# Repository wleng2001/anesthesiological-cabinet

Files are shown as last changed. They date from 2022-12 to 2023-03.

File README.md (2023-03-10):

# Anesthesiological-cabinet
 It's project of anesthesiological cabinet. Parts are saved in sldprt format. 
## Consist
It's consist of:
* welded body
* rack with height regulation with screw
* four wheel with bearings (it can rotate in 360°)
* runner for drawer

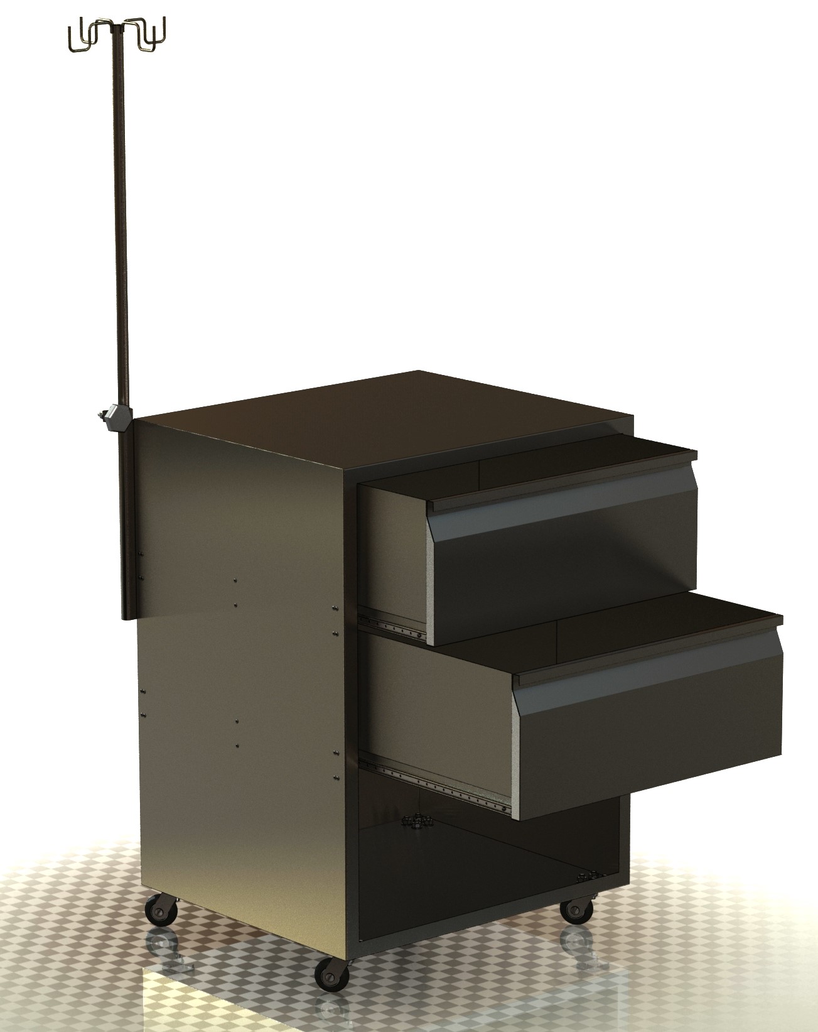
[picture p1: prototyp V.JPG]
It's photo of anesthesiological cabinet rendered in SolidWorks


What means normalized names of files:
* anc-1 it's main assembly
* anc-1-0001-0001 It's wheel assembly
	- anc-1-0001-0001-0001 It's bearing of the wheel assembly
	- anc-1-0001-0001-0002 It's fork fixing
	- anc-1-0001-0001-0003 It's rubbery pad
	- anc-1-0001-0001-0004 It's fork
	- anc-1-0001-0001-0005 It's special screw for wheel
	- anc-1-0001-0001-0006 It's wheel
	- anc-1-0001-0001-0007 It's tyre
* anc-1-0001-0002 It's rack assembly
* anc-1-0001-0003 it's drawer with runner assembly
	- anc-1-0001-0003-0001 It's drawer
	- anc-1-0001-0003-0002 It's fixing of drawer
	- anc-1-0001-0003-0003 It's rivet which fix runner to fixing of drawer
	- anc-1-0001-0003-0004 It's runner assembly
	- anc-1-0001-0003-0005 It's rivet which fix drawer to runner
* anc-1-0001-0004 It's corpus of cabinet
* anc-1-0001-0005 It's rivets, which fits drawer with runner to corpus.
* anc-1-0001-0006 It's rivets, which fits rack to corpus.
* anc-1-0001-0007 It's screw cover.

It's video, where you can see how is build wheel:
https://user-images.githubusercontent.com/112073988/213305082-b9180d91-3ac0-4ed8-8724-1e6955fea45c.mp4

In the technical drawing below you can see main assembly.
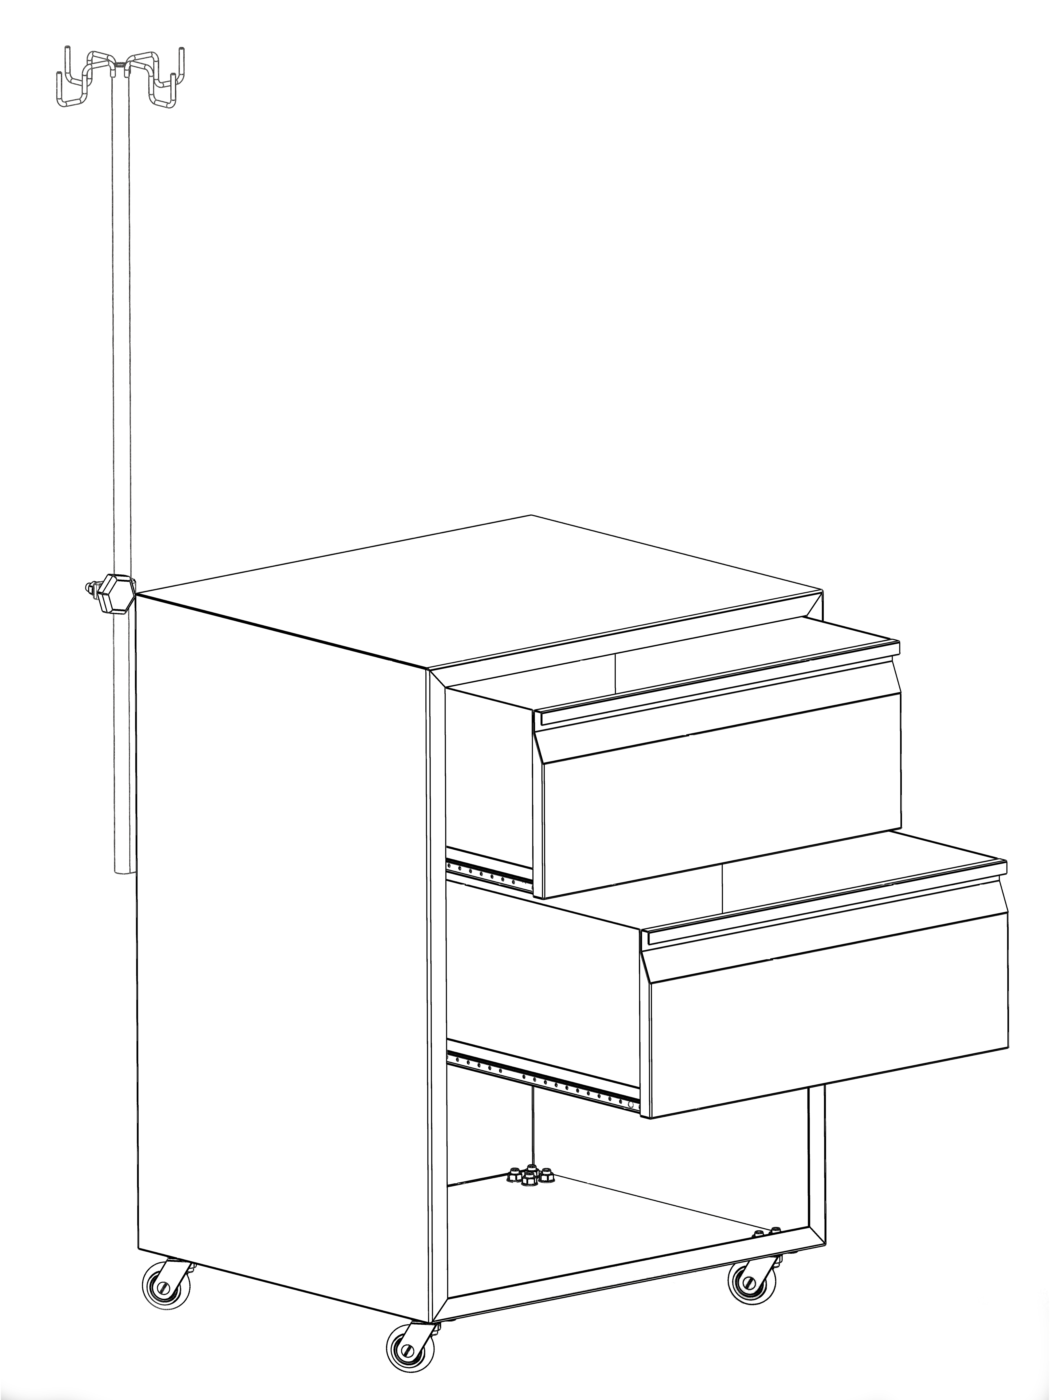
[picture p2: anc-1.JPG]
It's technical drawing of anesthesiological cabinet created in SolidWorks


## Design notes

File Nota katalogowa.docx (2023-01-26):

# Szafka anestezjologiczna anc-1

Nota katalogowa

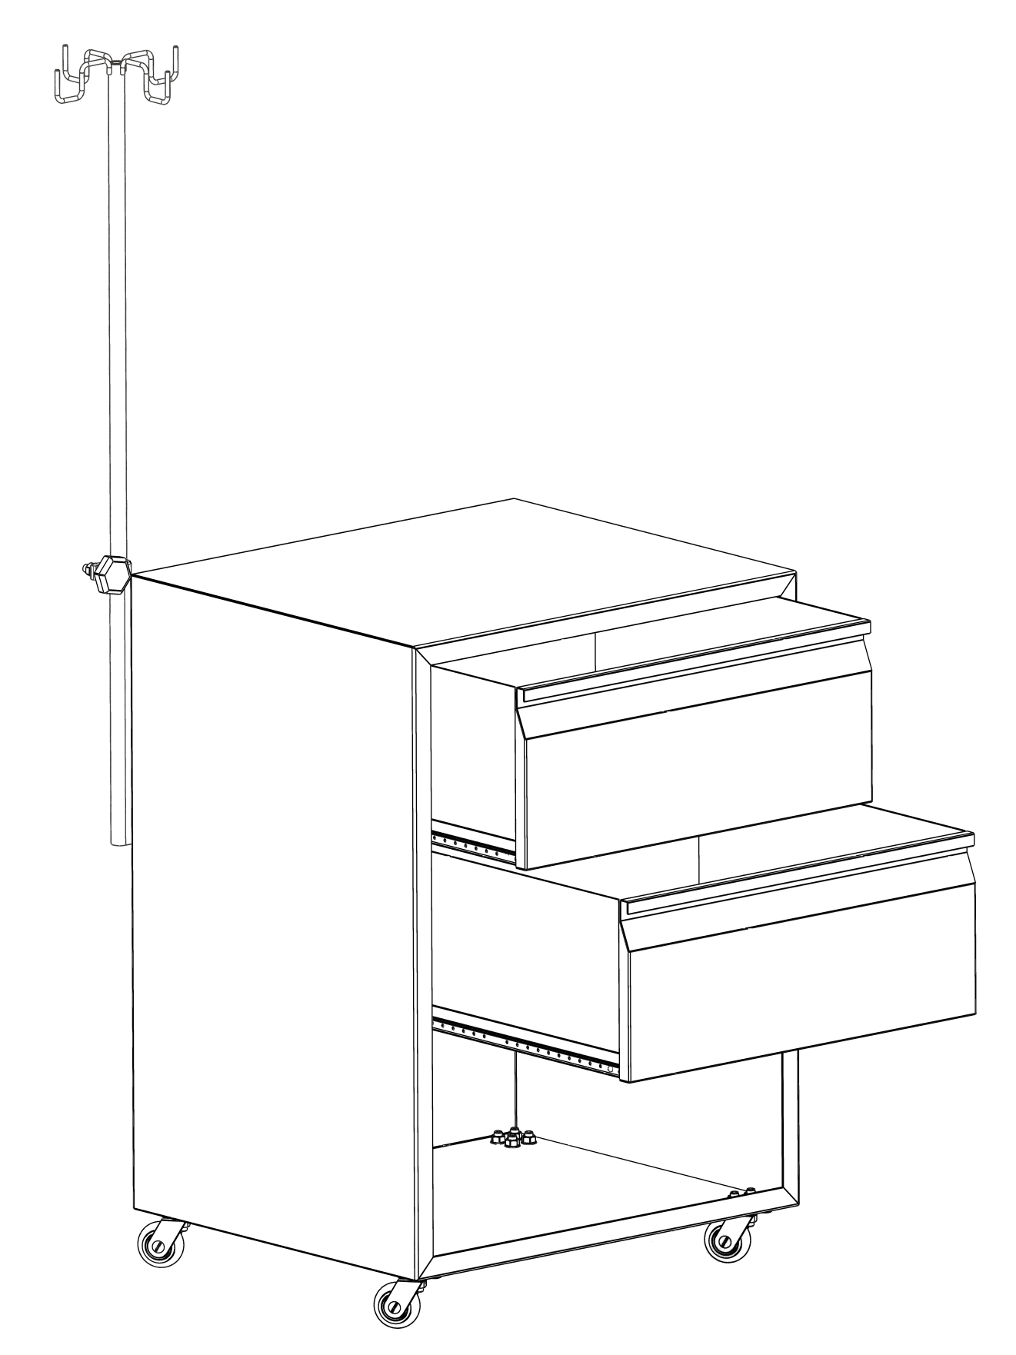
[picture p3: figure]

# Opis

Szafka dedykowana jest do użytku na salach operacyjnych dzięki zastosowaniu wysokiej klasy i wygodnej w czyszczeniu szczotkowanej stali nierdzewnej oraz wartościom użytkowym wynikającym z zastosowania wieszaka na kroplówki z szeroką regulacją wysokości oraz wysuwającym się daleko szufladom.

# Budowa szafki

Szafka składa się z czterech podstawowych elementów:

- korpusu,
- wózków w ilości czterech sztuk,
- szuflad w ilości dwóch sztuk,
- wieszaka.

Wózki wyposażone są w łożyska kulkowe a obrót wokół własnej osi opiera się w nich na łożyskach ślizgowych. Opona zbudowana jest z gumy zapewniając lepszą przyczepność wózka do podłoża oraz redukcję nierówności podczas przemieszczania szafki. Dodatkowe tłumienie nierówności zapewnia gumowa podkładka umieszczona na mocowaniu widelca. Wózki te zostały przymocowane do korpusu przy pomocy śrub M10.

Korpus ma długość 59cm, szerokość 69cm oraz wysokość 90cm i zbudowany jest z jednego arkusza 1mm giętej blachy spawanej na krawędziach w celu zapewnienia sztywności oraz nie pozwolenia na dostawanie się ewentualnych zanieczyszczeń do szuflad.

Szuflady wysuwają się na prowadnicach opartych na łożyskach kulkowych. Głębokość ich wynosi 25,6cm a długość 58cm . Przymocowane zostały do korpusu przy pomocy jednostronnych nitów.

Wieszak zapewnia regulację w zakresie od 102cm do 170cm od podłoża. Unieruchamia się go przy pomocy pokrętła umieszczonego tak, aby regulacja była jak najwygodniejsza. Przymocowany został do korpusu przy pomocy nitów jednostronnych.

Cała szafka waży 35kg a jej wymiary gabarytowe wynoszą na szerokość 82cm wysokość 138cm a długość 114cm.

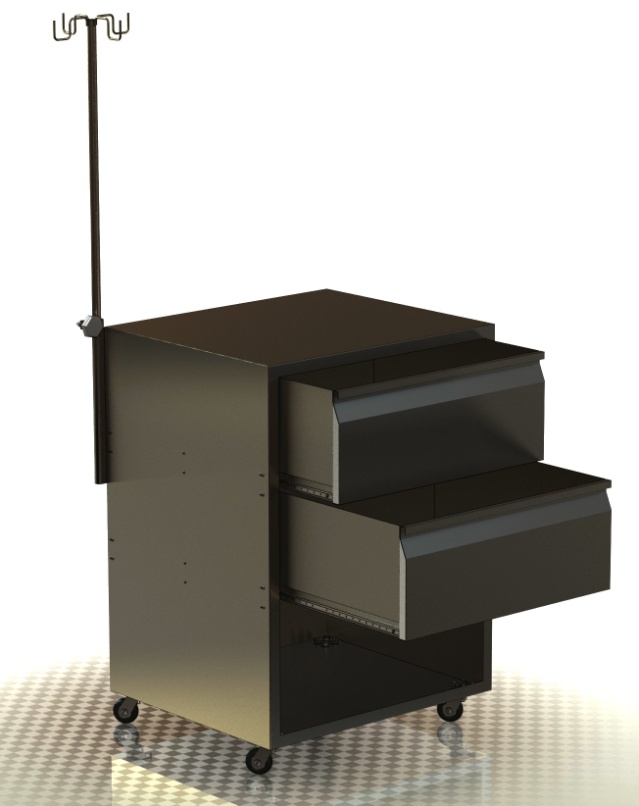
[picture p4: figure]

Zdjęcie 1 przedstawia szafkę w widoku od lewej.

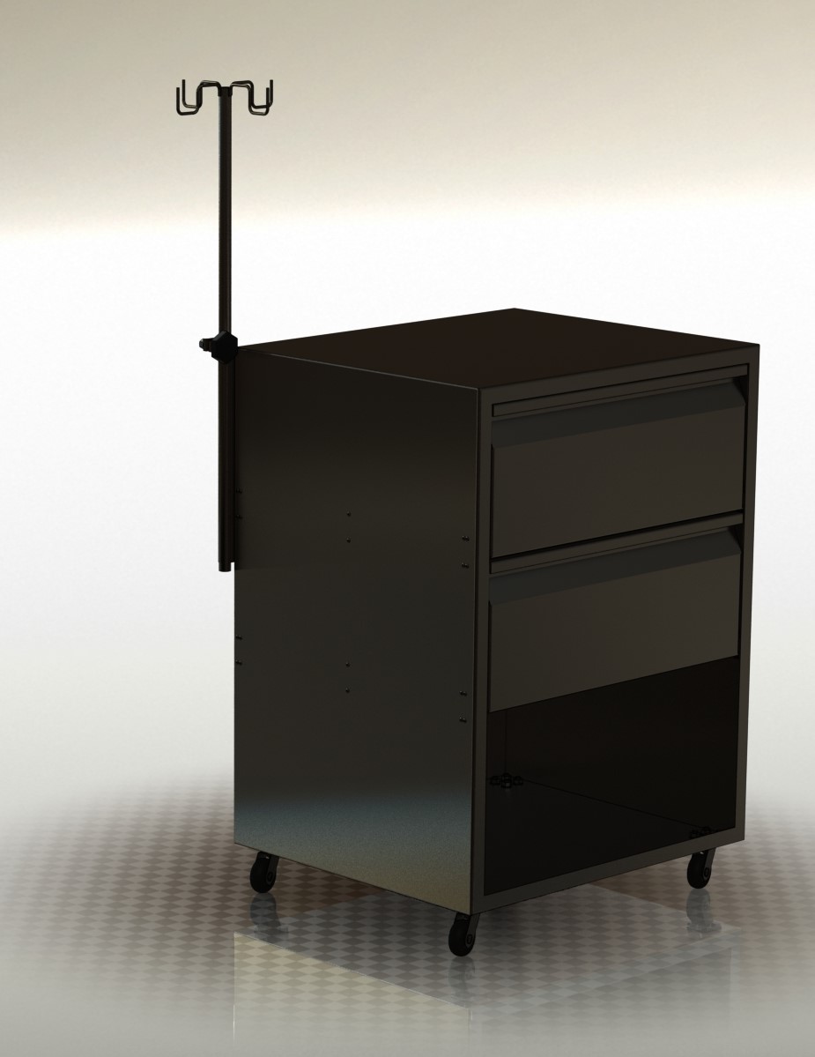
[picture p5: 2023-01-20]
prototyp IVa.JPG

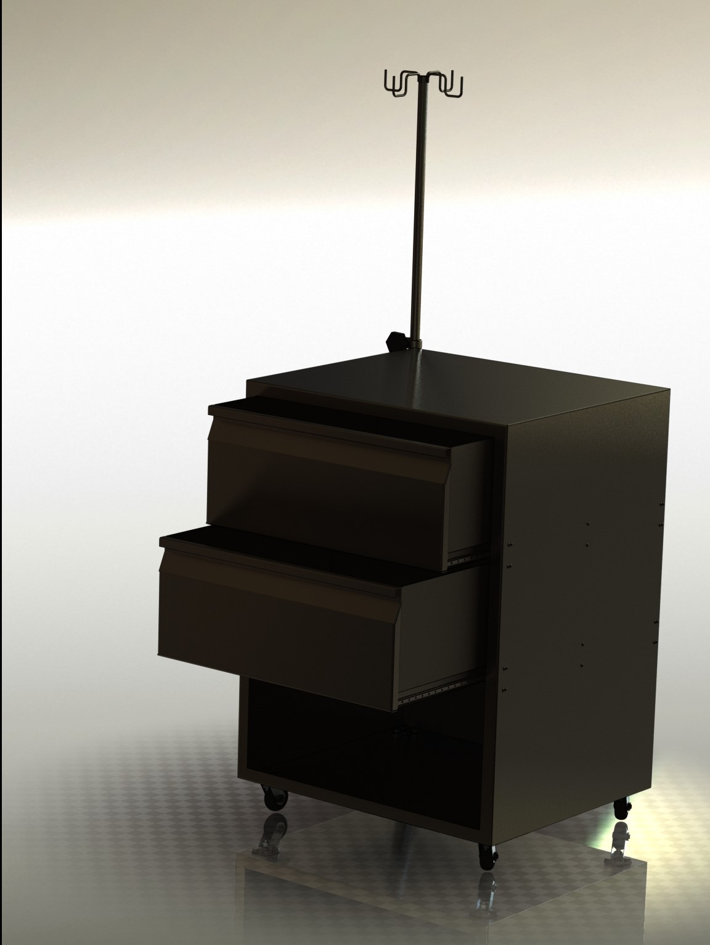
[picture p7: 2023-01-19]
prototyp IV.JPG

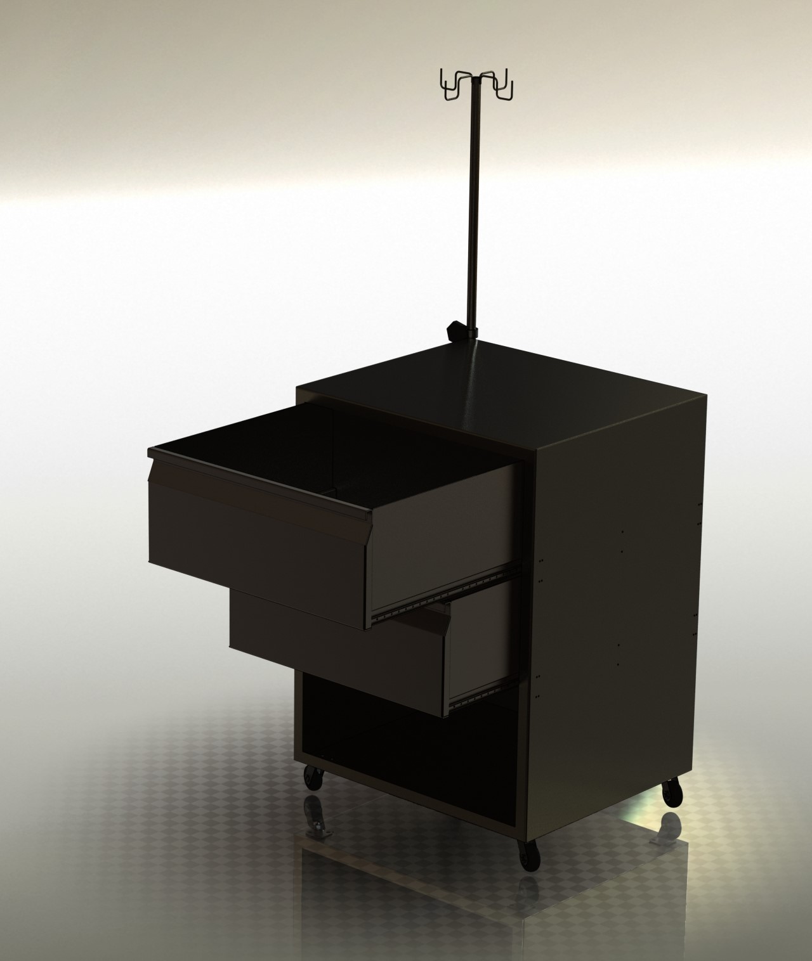
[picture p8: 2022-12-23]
prototyp III.JPG

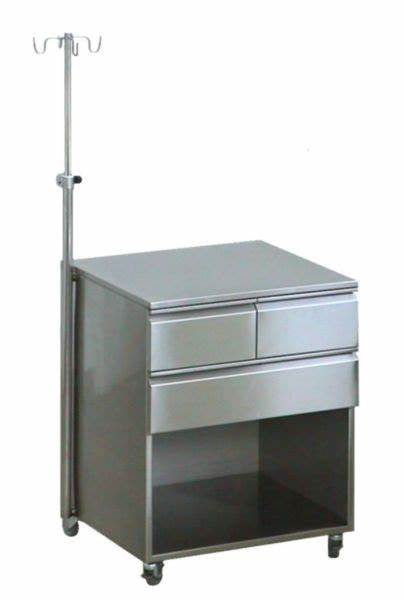
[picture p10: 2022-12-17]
inspiration photo.png

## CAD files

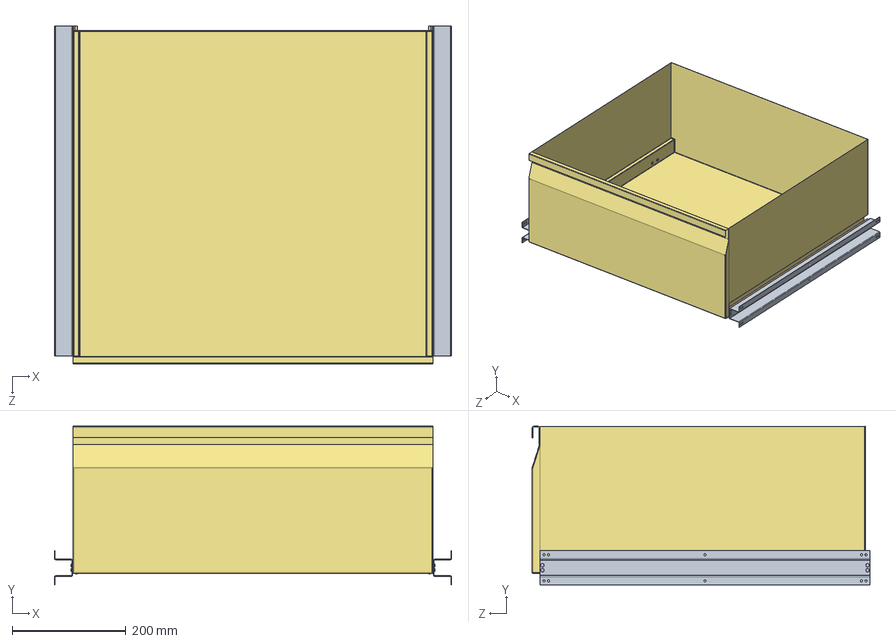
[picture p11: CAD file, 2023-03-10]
anc-1-0001-0003.SLDASM
698.0 x 279.0 x 594.1 mm
anc-1-0001-0003-0002 x 2
anc-1-0001-0003-0004-0001 x 2
anc-1-0001-0003-0004-0002 x 2
anc-1-0001-0003-0004-0003 x 2
anc-1-0001-0003-0004-0004 x 24
anc-1-0001-0003-0003 x 8
anc-1-0001-0003-0001
anc-1-0001-0003-0005 x 8

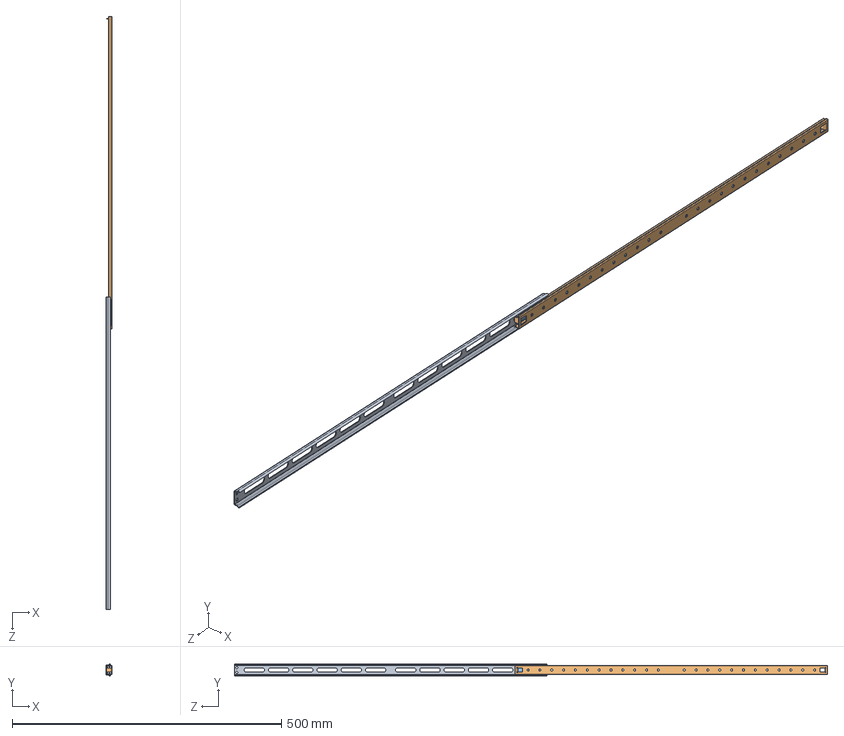
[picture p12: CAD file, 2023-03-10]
prowadnica/anc-1-0001-0003-0004.SLDASM
11.3 x 22.2 x 1101.1 mm
anc-1-0001-0003-0004-0001
anc-1-0001-0003-0004-0002
anc-1-0001-0003-0004-0003
anc-1-0001-0003-0004-0004 x 12

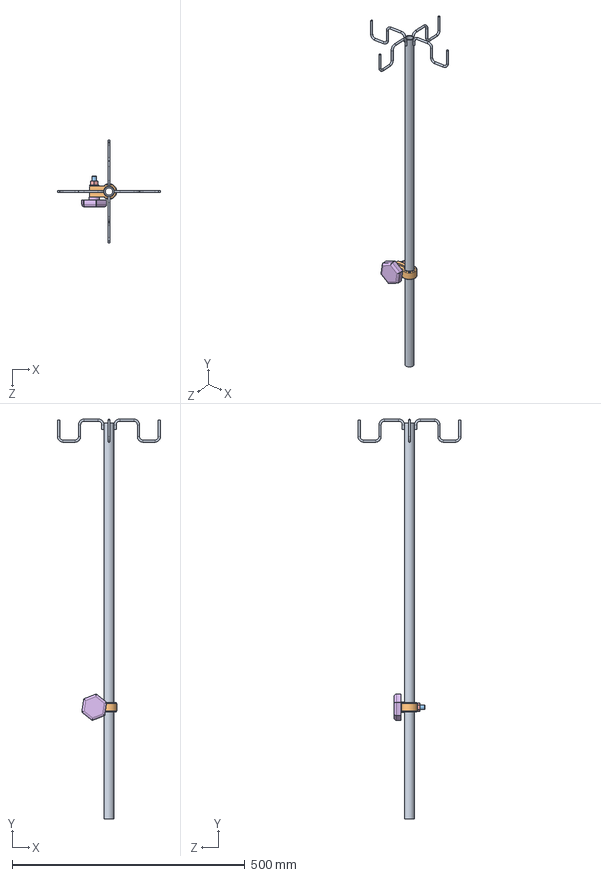
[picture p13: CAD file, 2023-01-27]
wieszak/anc-1-0001-0002.SLDASM
221.4 x 858.5 x 221.4 mm
anc-1-0001-0002-0003
hex bolt gradeab_iso
plain washer 10673 type snl_iso
anc-1-0001-0002-0002
hex nut gradec_iso
anc-1-0001-0001-0002-0004

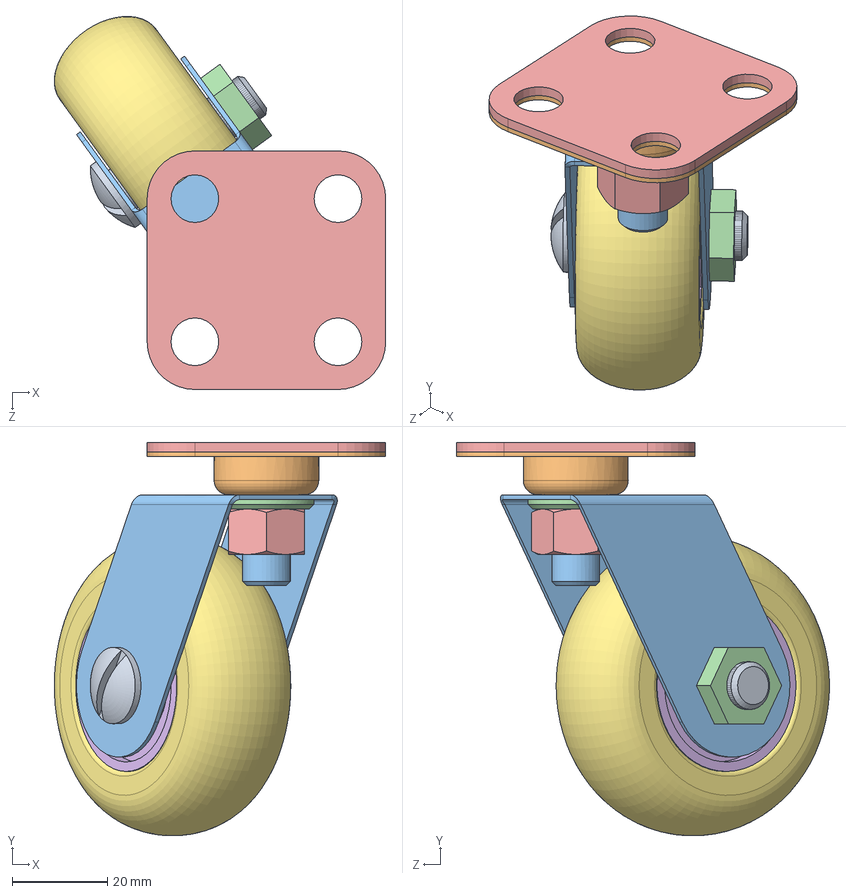
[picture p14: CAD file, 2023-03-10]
wózek/anc-1-0001-0001.SLDASM
69.5 x 82.5 x 78.2 mm
anc-1-0001-0001-0002
anc-1-0001-0001-0004
plain washer chamfered grade a_2_iso
hex nut gradec_iso
anc-1-0001-0001-0001-0006
anc-1-0001-0001-0001-0007
anc-1-0001-0001-0001-0002 x 2
anc-1-0001-0001-0001-0003 x 2
anc-1-0001-0001-0001-0001 x 32
hex screw gradeab_iso
anc-1-0001-0001-0001-0005
hex thin nut gradeb_iso
anc-1-0001-0001-0003
circlip for bores normal_din x 2

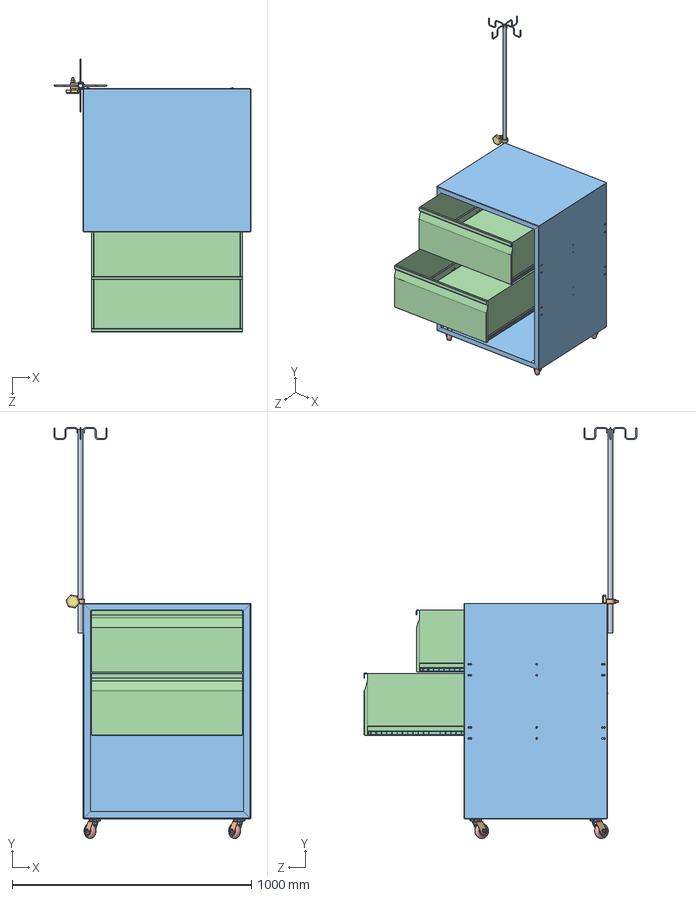
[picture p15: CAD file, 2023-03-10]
anc-1.SLDASM
822.6 x 1716.8 x 1139.1 mm
anc-1-0001-0004
anc-1-0001-0002-0003
hex bolt gradeab_iso
plain washer 10673 type snl_iso
anc-1-0001-0002-0002
hex nut gradec_iso x 5
anc-1-0001-0001-0002-0004
anc-1-0001-0006 x 4
anc-1-0001-0001-0002 x 4
anc-1-0001-0001-0004 x 4
plain washer chamfered grade a_2_iso x 4
anc-1-0001-0001-0001-0006 x 4
anc-1-0001-0001-0001-0007 x 4
anc-1-0001-0001-0001-0002 x 8
anc-1-0001-0001-0001-0003 x 8
anc-1-0001-0001-0001-0001 x 128
hex screw gradeab_iso x 20
anc-1-0001-0001-0001-0005 x 4
hex thin nut gradeb_iso x 4
anc-1-0001-0001-0003 x 4
circlip for bores normal_din x 8
anc-1-0001-0003-0002 x 4
anc-1-0001-0003-0004-0001 x 4
anc-1-0001-0003-0004-0002 x 4
anc-1-0001-0003-0004-0003 x 4
anc-1-0001-0003-0004-0004 x 48
anc-1-0001-0003-0003 x 16
anc-1-0001-0003-0001 x 2
anc-1-0001-0003-0005 x 16
anc-1-0001-0005 x 40
plain washer normal grade a_iso x 16
hex nut style 1 gradeab_iso x 16
anc-1-0001-0007 x 16

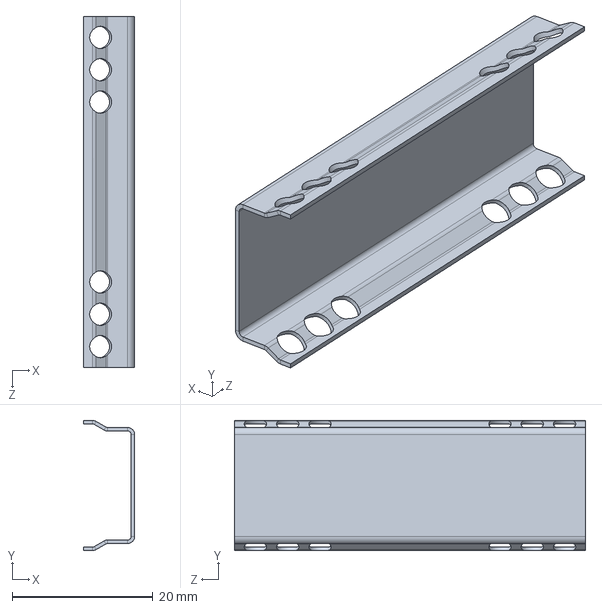
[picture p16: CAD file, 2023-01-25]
prowadnica/anc-1-0001-0003-0004-0003.SLDPRT
7.32 x 18.5 x 50.0 mm

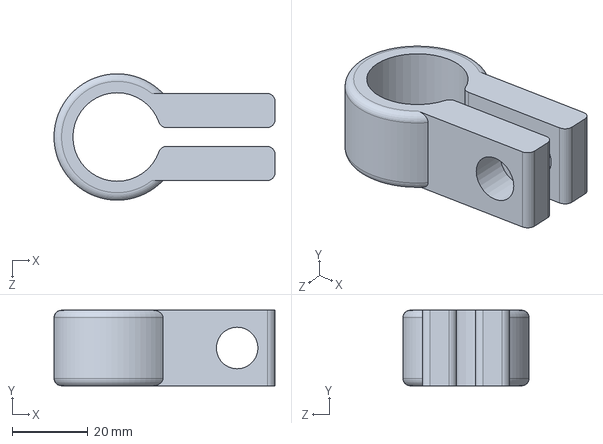
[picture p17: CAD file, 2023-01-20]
wieszak/anc-1-0001-0002-0003.SLDPRT
58.4 x 20.0 x 33.4 mm

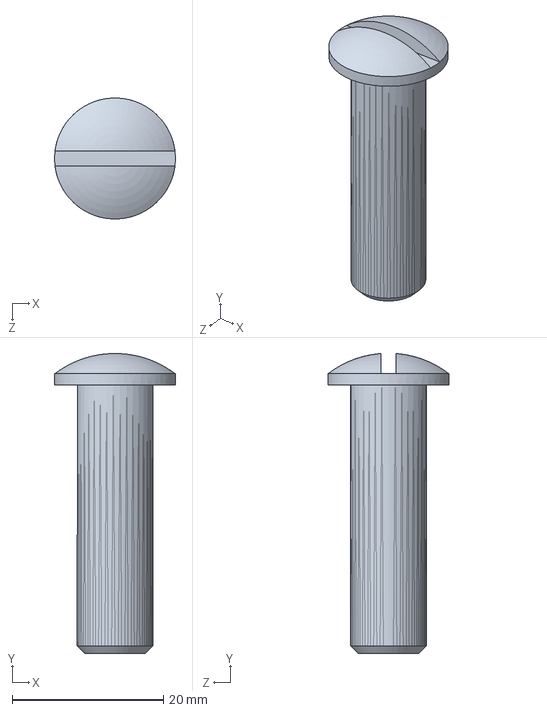
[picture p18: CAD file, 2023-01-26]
wózek/anc-1-0001-0001-0001-0005.SLDPRT
16.0 x 39.7 x 16.0 mm

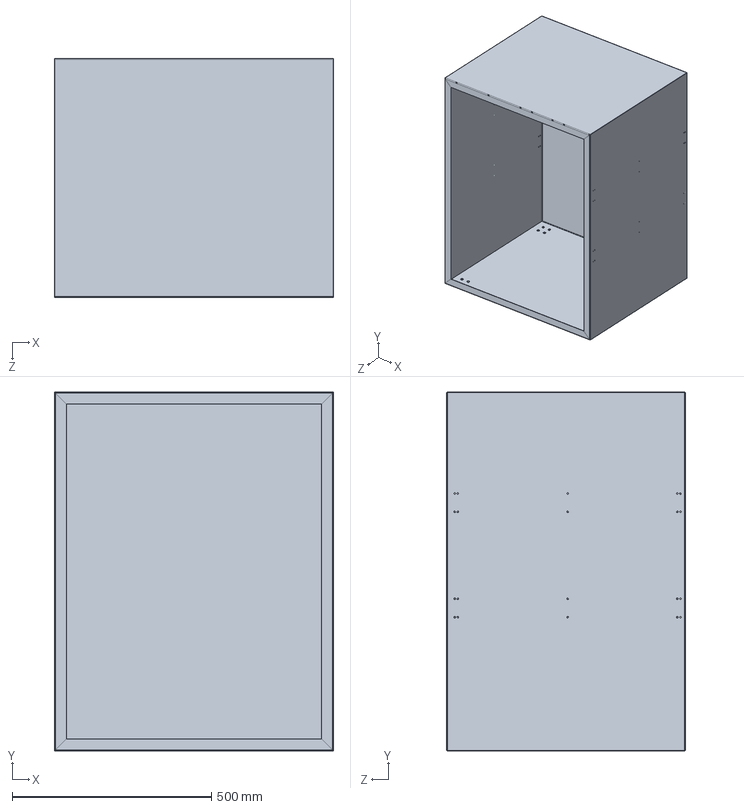
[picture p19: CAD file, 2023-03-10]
anc-1-0001-0004.SLDPRT
700.0 x 900.0 x 600.0 mm

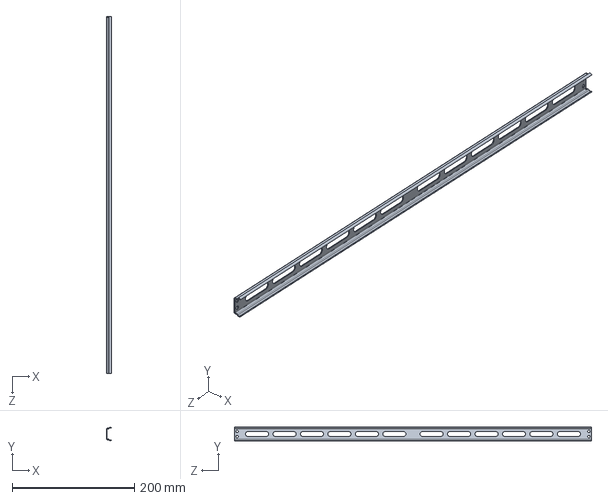
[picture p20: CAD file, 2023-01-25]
prowadnica/anc-1-0001-0003-0004-0001.SLDPRT
8.73 x 22.2 x 585.0 mm

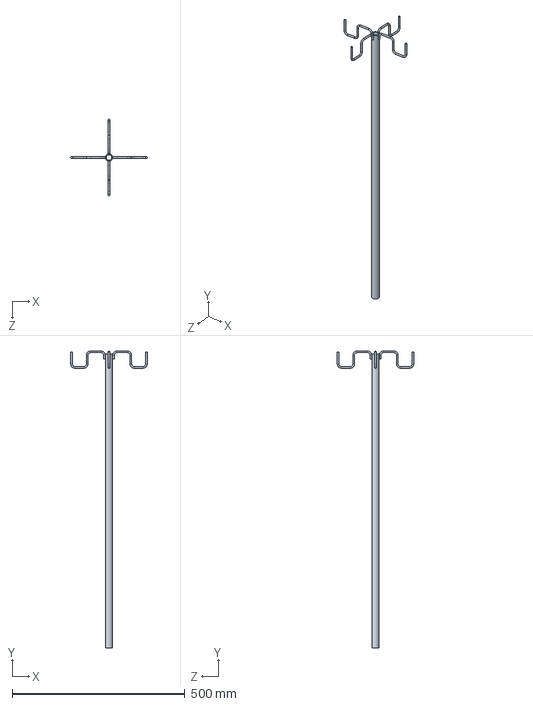
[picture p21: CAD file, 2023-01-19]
wieszak/anc-1-0001-0002-0002.SLDPRT
221.4 x 858.5 x 221.4 mm

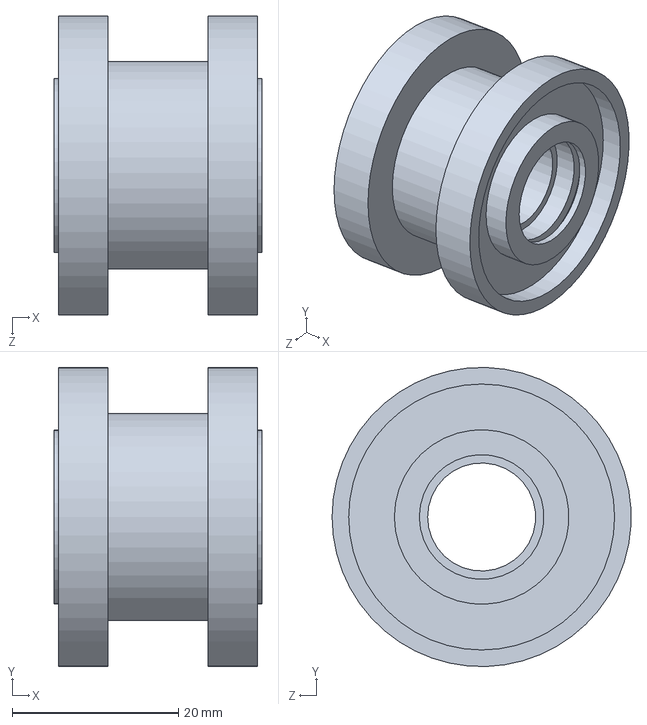
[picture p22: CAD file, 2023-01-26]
wózek/anc-1-0001-0001-0001-0006.SLDPRT
25.0 x 36.0 x 36.0 mm

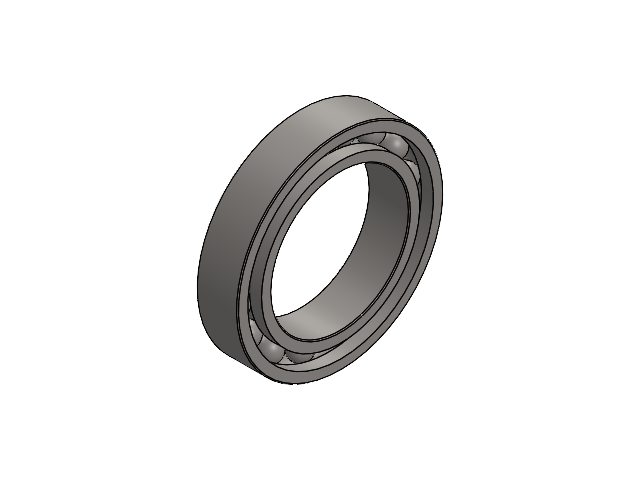
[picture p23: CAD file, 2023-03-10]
wózek/łożysko/anc-1-0001-0001-0001.SLDASM
anc-1-0001-0001-0001-0002
anc-1-0001-0001-0001-0003
anc-1-0001-0001-0001-0001 x 16

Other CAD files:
wózek/łożysko/Lustroanc-1-0001-0001-00011.SLDASM
wózek/łożysko/Lustroanc-1-0001-0001-0001.SLDASM
wózek/Lustroanc-1-0001-0001.SLDASM
wózek/łożysko/Lustroanc-1-0001-0001-0001-0001.SLDPRT
wózek/łożysko/Lustroanc-1-0001-0001-0001-0002.SLDPRT
CopyDesignTemp/aplikacje/browser/iso/bolts and screws/hex bolts and screws/hex bolt gradeab_iso.sldprt
CopyDesignTemp/aplikacje/browser/iso/nuts/hex nuts/hex nut gradec_iso1.sldprt
CopyDesignTemp/aplikacje/browser/iso/washers/plain washers/plain washer chamfered grade a_2_iso.SLDPRT
anc-1-0001-0003-0001.SLDPRT
anc-1-0001-0003-0002.SLDPRT
anc-1-0001-0003-0003.SLDPRT
anc-1-0001-0003-0005.SLDPRT
anc-1-0001-0005.SLDPRT
anc-1-0001-0006.SLDPRT
anc-1-0001-0007.SLDPRT
anc-1.SLDDRW
hex nut style 1 gradeab_iso.SLDPRT
hex screw gradeab_iso.SLDPRT
nit zużyty.SLDPRT
nit.SLDPRT
plain washer normal grade a_iso.SLDPRT
prowadnica/anc-1-0001-0003-0004-0002.SLDPRT
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

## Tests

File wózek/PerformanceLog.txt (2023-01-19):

Number of Contacts: 271
Number of contact data: 12600

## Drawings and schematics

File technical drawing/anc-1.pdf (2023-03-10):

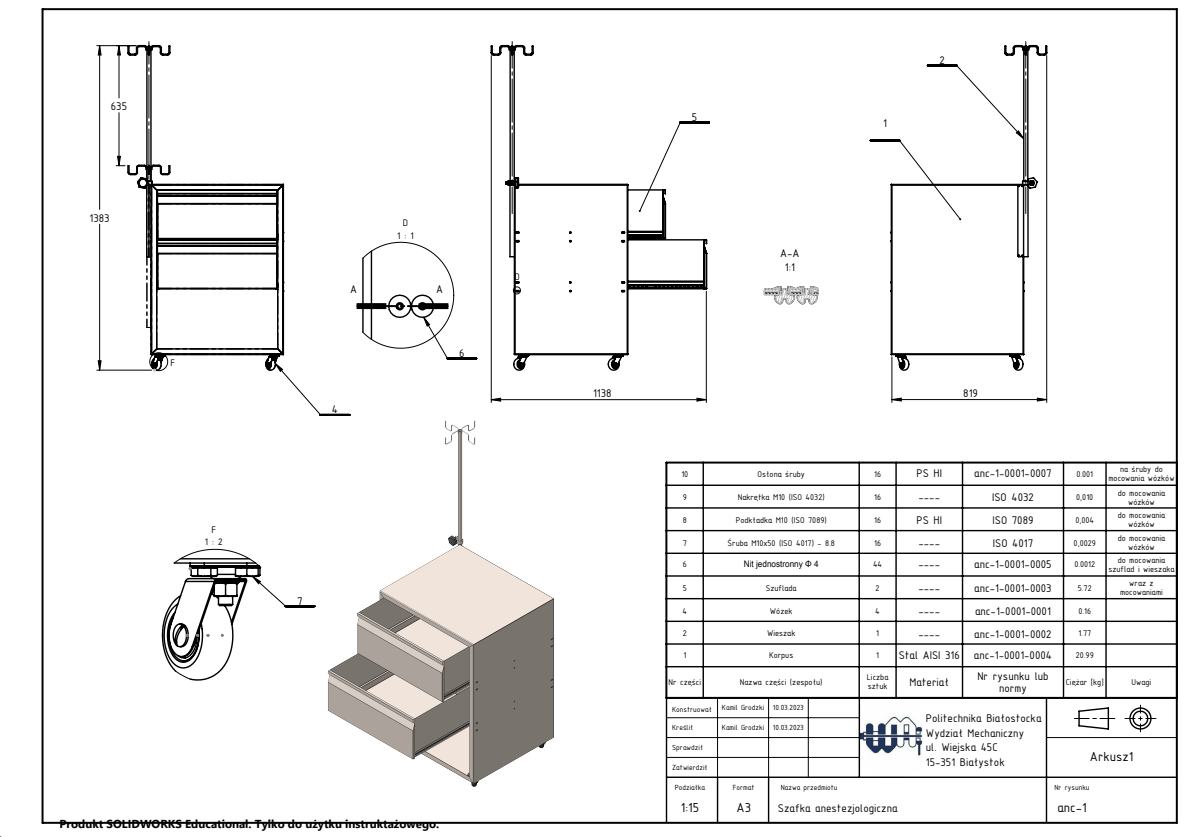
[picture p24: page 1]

10 | Osłona śruby | 16 | PS HI | anc-1-0001-0007 | 0.001 | na śruby do mocowania wózków

9 | Nakrętka M10 (ISO 4032) | 16 | ---- | ISO 4032 | 0,010 | do mocowania wózków

8 | Podkładka M10 (ISO 7089) | 16 | PS HI | ISO 7089 | 0,004 | do mocowania wózków

7 | Śruba M10x50 (ISO 4017) - 8.8 | 16 | ---- | ISO 4017 | 0,0029 | do mocowania wózków

6 | Nit jednostronny Φ 4 | 44 | ---- | anc-1-0001-0005 | 0.0012 | do mocowania szuflad i wieszaka

5 | Szuflada | 2 | ---- | anc-1-0001-0003 | 5.72 | wraz z mocowaniami
4 | Wózek | 4 | ---- | anc-1-0001-0001 | 0.16
2 | Wieszak | 1 | ---- | anc-1-0001-0002 | 1.77
1 | Korpus | 1 | Stal AISI 316 | anc-1-0001-0004 | 20.99

Nr części | Nazwa części (zespołu) | sztuk Liczba | Materiał | Nr rysunku lub normy | Ciężar [kg] | Uwagi

Konstruował | Kamil Grodzki | 10.03.2023 | | Politechnika Białostocka Wydział Mechaniczny ul. Wiejska 45C 15-351 Białystok

Kreślił | Kamil Grodzki | 10.03.2023
Sprawdził | | | | | Arkusz1

Zatwierdził
Podziałka 1:15 | Format A3 | Nazwa przedmiotu Szafka anestezjologiczna | | | Nr rysunku anc-1

Produkt SOLIDWORKS Educational. Tylko do użytku instruktażowego.

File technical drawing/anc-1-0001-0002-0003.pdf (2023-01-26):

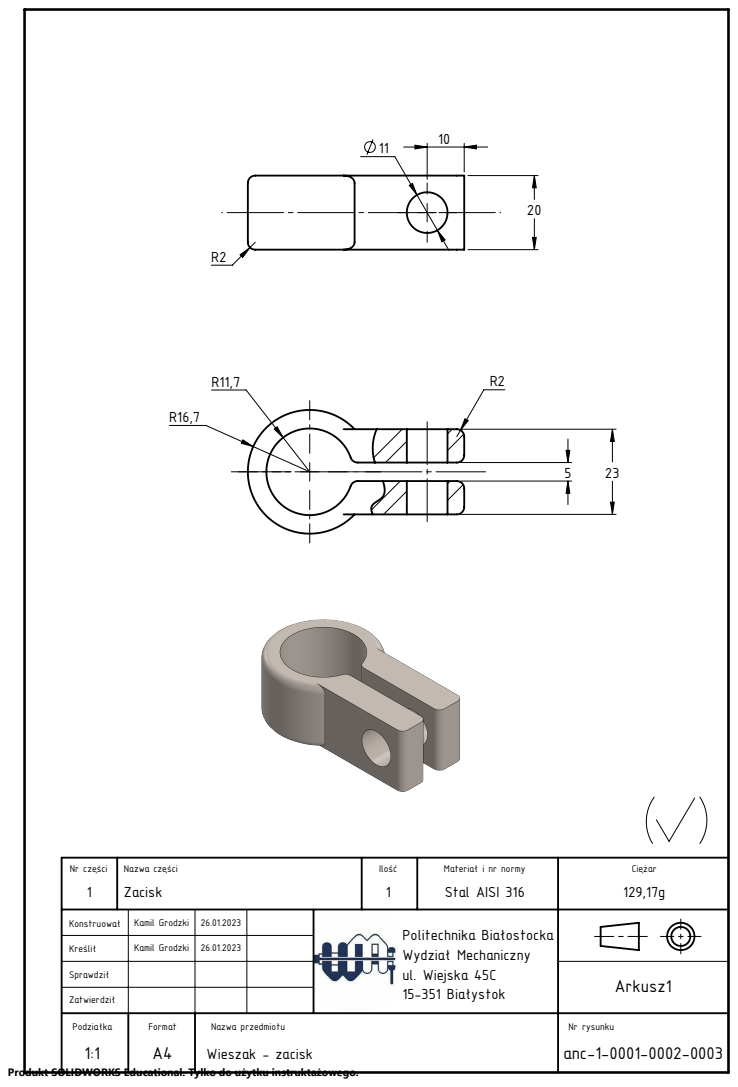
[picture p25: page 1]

Nr części 1 | Nazwa części Zacisk | Ilość 1 | Materiał i nr normy Stal AISI 316 | Ciężar 129,17g

Konstruował | Kamil Grodzki | 26.01.2023 | | Politechnika Białostocka Wydział Mechaniczny ul. Wiejska 45C 15-351 Białystok

Kreślił | Kamil Grodzki | 26.01.2023
Sprawdził | | | | | Arkusz1

Zatwierdził
Podziałka 1:1 | Format A4 | Nazwa przedmiotu Wieszak - zacisk | | | Nr rysunku anc-1-0001-0002-0003

Produkt SOLIDWORKS Educational. Tylko do użytku instruktażowego.

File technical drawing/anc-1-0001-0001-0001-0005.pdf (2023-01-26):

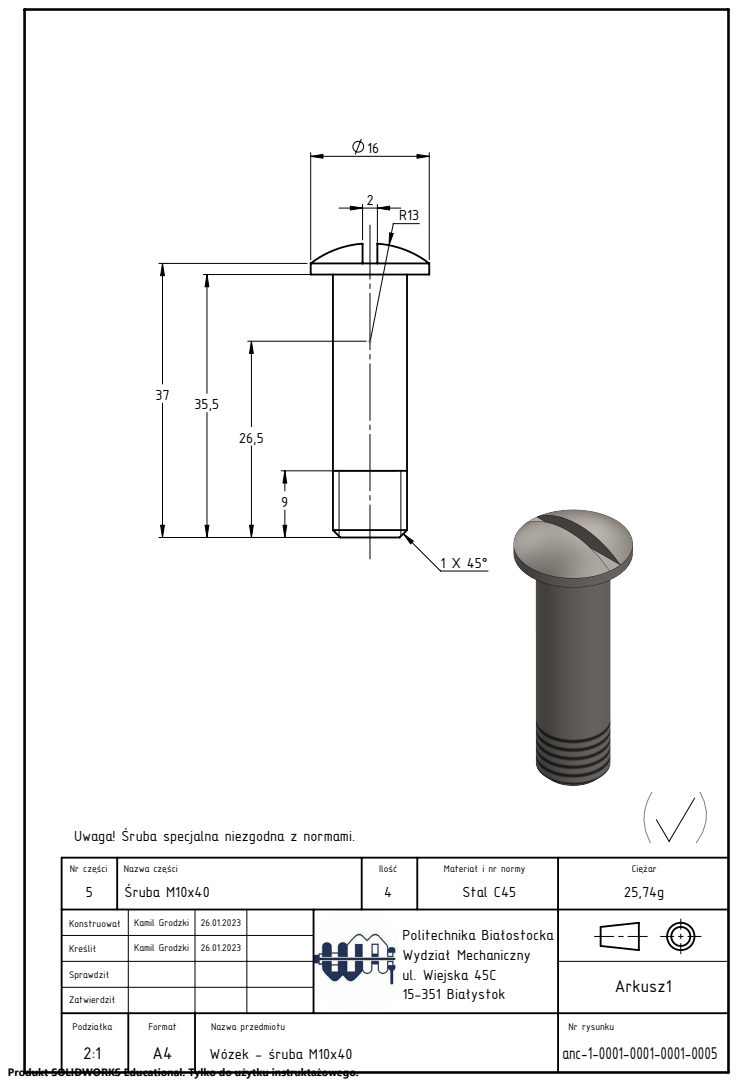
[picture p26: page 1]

Uwaga! Śruba specjalna niezgodna z normami.

Nr części 5 | Nazwa części Śruba M10x40 | Ilość 4 | Materiał i nr normy Stal C45 | Ciężar 25,74g

Konstruował | Kamil Grodzki | 26.01.2023 | | Politechnika Białostocka Wydział Mechaniczny ul. Wiejska 45C 15-351 Białystok

Kreślił | Kamil Grodzki | 26.01.2023
Sprawdził | | | | | Arkusz1

Zatwierdził
Podziałka 2:1 | Format A4 | Nazwa przedmiotu Wózek - śruba M10x40 | | | Nr rysunku anc-1-0001-0001-0001-0005

Produkt SOLIDWORKS Educational. Tylko do użytku instruktażowego.

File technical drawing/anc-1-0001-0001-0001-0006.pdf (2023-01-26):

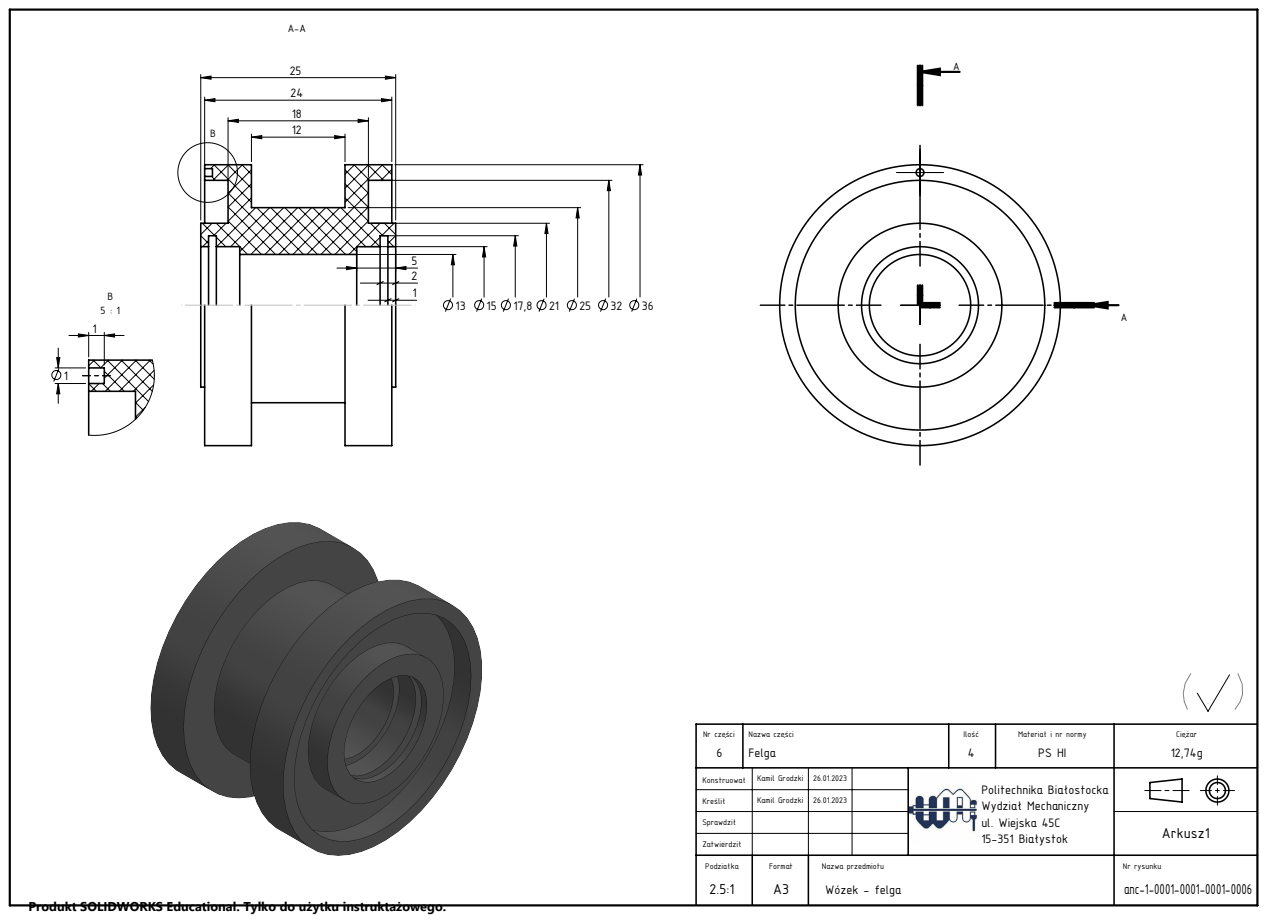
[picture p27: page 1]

Nr części 6 | Nazwa części Felga | Ilość 4 | Materiał i nr normy PS HI | Ciężar 12,74g

Konstruował | Kamil Grodzki | 26.01.2023 | | Politechnika Białostocka Wydział Mechaniczny ul. Wiejska 45C 15-351 Białystok

Kreślił | Kamil Grodzki | 26.01.2023
Sprawdził | | | | | Arkusz1

Zatwierdził
Podziałka 2.5:1 | Format A3 | Nazwa przedmiotu Wózek - felga | | | Nr rysunku anc-1-0001-0001-0001-0006

Produkt SOLIDWORKS Educational. Tylko do użytku instruktażowego.

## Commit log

2022-12-17 add runner for drawer
    [forma ograniczenia wysuwu.SLDPRT, korpus.SLDPRT, kulka 3,2mm.SLDPRT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]
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2022-12-17 add drawer runner to assembly (szafka anestezjologiczna.SLDASM)
    [korpus.SLDPRT, kulka 3,2mm.SLDPRT, mocowanie kulek.SLDPRT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]
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2022-12-17 add minor correction
    [prowadnica.SLDASM, szafka anestezjologiczna.SLDASM, wieszak złożenie.SLDASM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]
2022-12-19 add stl file of all anesthesiological cabinet
    [prowadnica.SLDASM, szafka anestezjologiczna.SLDASM, wieszak złożenie.SLDASM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]
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2022-12-21 add rivent to runners
    [nit zużyty prowadnica-mocowanie.SLDPRT, prowadnica.SLDASM, wieszak złożenie.SLDASM]
2022-12-22 add drawer to assembly
    [korpus 2.SLDPRT, korpus.SLDPRT, mocowanie prowadnicy.SLDPRT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]
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2022-12-23 add hole for rivets
    [korpus.SLDPRT, pokrętło.SLDPRT, prowadnica.SLDASM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]
2022-12-23 add photo of new assembly
    [prowadnica.SLDASM, wózek.SLDASM, łożysko złożenie.SLDASM]
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2023-01-13 add segers in wheel
    [felga koła.SLDPRT, hex nut gradec_iso.SLDPRT, hex screw gradeab_iso.SLDPRT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]
2023-01-13 add snap-ring for bearings in wheel
    [szafka anestezjologiczna 2.SLDASM, wózek.SLDASM, łożysko złożenie.SLDASM]
2023-01-18 add segers to wheel
    [felga koła.SLDPRT, mocowanie prowadnicy.SLDPRT, prowadnica.SLDASM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]
2023-01-18 change names to normalized in wheel
    [anc-1-0001-0001-0001-0001.SLDPRT, anc-1-0001-0001-0001-0002.SLDPRT, anc-1-0001-0001-0001-0003.SLDPRT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]
2023-01-18 change names in rack to normalized
    [anc-1-0001-0001-0001-0006.SLDPRT, anc-1-0001-0001-0001.SLDASM, anc-1-0001-0001-0002-0004.SLDPRT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]
2023-01-18 change name in drawer with runner to normalized
    [anc-1-0001-0001-0001-0005.SLDDRW, anc-1-0001-0001-0001-0005.SLDPRT, anc-1-0001-0001-0001.SLDASM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]
2023-01-18 change names in drawer to normalized
    [anc-1-0001-0003-0004-0001.SLDPRT, anc-1-0001-0003-0004-0002.SLDPRT, anc-1-0001-0003-0004-0003.SLDPRT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]
2023-01-18 add information about names in README
    [anc-1-0001-0001-0001.SLDASM, anc-1-0001-0001.SLDASM, anc-1.SLDASM]
2023-01-18 add exploded view to wheel assembly
    [anc-1-0001-0001-0001.SLDASM, anc-1-0001-0001.SLDASM, anc-1.SLDASM]
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2023-01-18 repair mistake with rack
    [anc-1-0001-0001-0001.SLDASM, anc-1-0001-0001.SLDASM, anc-1-0001-0002-0001.SLDPRT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]
2023-01-18 normalized name of corpus to ans-1-0001-0004
    [anc-1-0001-0004.SLDPRT, anc-1.SLDASM, korpus.SLDPRT]
2023-01-19 add rivetts to main assembly
    add rivets to main assembly and description where they are
    [anc-1-0001-0001-0001.SLDASM, anc-1-0001-0001.SLDASM, anc-1-0001-0002.SLDASM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]
2023-01-19 add normalized for rivets, which fit rack to corpus
    [Lustroanc-1-0001-0001-0001-0001.SLDPRT, Lustroanc-1-0001-0001-0001-0002.SLDPRT, Lustroanc-1-0001-0001-0001-0003.SLDPRT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]
2023-01-19 change look of drawer
    [anc-1-0001-0001-0001-0006.SLDPRT, anc-1-0001-0001-0001-0007.SLDPRT, anc-1-0001-0001-0001.SLDASM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]
2023-01-19 fit wheel assembly to corpus by screws
    [anc-1-0001-0001-0001.SLDASM, anc-1-0001-0001-0002.SLDPRT, anc-1-0001-0001.SLDASM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]
2023-01-19 add new photo to readme and stl file of main assembly
    [anc-1-0001-0001-0001.SLDASM, anc-1-0001-0001.SLDASM, anc-1-0001-0003-0004.SLDASM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]
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2023-01-19 add new configuration of main assembly
    [anc-1-0001-0001-0001.SLDASM, anc-1-0001-0001.SLDASM, anc-1-0001-0002.SLDASM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]
2023-01-19 add technical drawing
    technical drawing of corpus, screw to wheel assembly and clip to rack
    [anc-1-0001-0001-0001-0005.SLDDRW, anc-1-0001-0001-0001-0005.SLDPRT, anc-1-0001-0001-0001.SLDASM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]
2023-01-19 add description of part of wheel assembly
    [anc-1-0001-0004.SLDDRW]
2023-01-19 add technical drawing of wheel
    [anc-1-0001-0001-0001-0006.SLDDRW, anc-1-0001-0001-0001-0006.SLDPRT]
2023-01-19 minor change in technical drawing
    [anc-1-0001-0001-0001-0006.SLDDRW, anc-1-0001-0001.SLDASM, anc-1-0001-0003-0004.SLDASM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]
2023-01-20 repair technical drawing
    Correct mistakes in technical drawing of wheel, screw and clip. Create pdf file of it too.
    [anc-1-0001-0001-0001-0005.SLDDRW, anc-1-0001-0001-0001-0005.SLDPRT, anc-1-0001-0001-0001-0006.SLDDRW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]
2023-01-24 repair mistakes in screw technical drawing
    [anc-1-0001-0001-0001-0005.SLDDRW, anc-1-0001-0001-0001-0005.SLDPRT, anc-1-0001-0001-0001-0006.SLDDRW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]
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2023-01-24 change sheet of metal to thinner for drawer
    [anc-1-0001-0001-0001-0005.SLDDRW, anc-1-0001-0001-0001-0006.SLDDRW, anc-1-0001-0001-0001.SLDASM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]
2023-01-24 add rivets, which fix drawer to runner
    [anc-1-0001-0003-0004.SLDASM, anc-1-0001-0003-0005.SLDPRT, anc-1-0001-0003.SLDASM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]
2023-01-24 repair mistake with bearings in runner
    [anc-1-0001-0002.SLDASM, anc-1-0001-0003-0002.SLDPRT, anc-1-0001-0003-0004-0003.SLDPRT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]
2023-01-24 repair minor mistakes
    [anc-1-0001-0002.SLDASM, anc-1-0001-0003-0004.SLDASM, anc-1-0001-0003-0005.SLDPRT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]
2023-01-25 repair mistakes in technical drawing
    [anc-1-0001-0001-0001-0005.SLDDRW, anc-1-0001-0001-0001-0006.SLDDRW, anc-1-0001-0001.SLDASM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]
2023-01-25 add technical drawing of main assembly
    add technical drawing of main assembly in pdf and jpg format. Remove technical drawing of corpus.
    [anc-1-0001-0001-0001.SLDASM, anc-1-0001-0001.SLDASM, anc-1-0001-0002.SLDASM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]
2023-01-25 repair mistake with display technical drawing
    Repair mistake with display technical drawing of main assembly in README.MD
2023-01-25 correct mistakes in clamp technical drawing
    [anc-1-0001-0001.SLDASM, anc-1-0001-0002-0003.SLDDRW, anc-1-0001-0002.SLDASM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]
2023-01-25 repair mistakes in technical drawing of wheel
    [anc-1-0001-0001-0001-0006.SLDDRW]
2023-01-25 correct mistakes in documentation
    [anc-1-0001-0001-0001-0005.SLDDRW, anc-1-0001-0001-0001.SLDASM, anc-1-0001-0001.SLDASM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]
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2023-01-26 add minor changes to wheel screw technical drawing
    [anc-1-0001-0001-0001-0005.SLDDRW, anc-1-0001-0001-0001-0005.SLDPRT]
2023-01-26 add minor visual changes in technical drawing of rack clamp
    [anc-1-0001-0001.SLDASM, anc-1-0001-0002-0003.SLDDRW, anc-1-0001-0003-0004.SLDASM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]
2023-01-26 repair mistake in drawer assembly
    Repair mistake with to narrow drawer
    [anc-1-0001-0001.SLDASM, anc-1-0001-0003-0002.SLDPRT, anc-1-0001-0003-0003.SLDPRT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]
2023-01-26 add changes in technical drawing of main assembly
    add section of example rivets in corpus
    [anc-1-0001-0001.SLDASM, anc-1-0001-0002.SLDASM, anc-1-0001-0003-0004.SLDASM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]
2023-01-26 change photo of technical drawing of main assembly
    [anc-1-0001-0003-0004.SLDASM, anc-1-0001-0003-0005.SLDPRT, anc-1-0001-0003.SLDASM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]
2023-01-26 add changes in technical drawing of main assembly
    [anc-1-0001-0002.SLDASM, anc-1-0001-0003-0004.SLDASM, anc-1-0001-0003-0005.SLDPRT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]
2023-01-26 add minor changes in technical drawing of main assembly
    [anc-1-0001-0003-0004.SLDASM, anc-1.SLDASM]
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2023-03-10 repair minor mistakes in technical drawing
    repair minor mistakes in technical drawing of main assembly and documentation
    [anc-1-0001-0001.SLDASM, anc-1-0001-0003-0004.SLDASM, anc-1-0001-0003-0005.SLDPRT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]
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2023-03-10 add screw cover to main assembly technical drawing
    [anc-1-0001-0001.SLDASM, anc-1-0001-0003-0004.SLDASM, anc-1-0001-0003-0005.SLDPRT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]
